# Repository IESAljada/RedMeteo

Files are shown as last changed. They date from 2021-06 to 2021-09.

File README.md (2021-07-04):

# RedMeteo
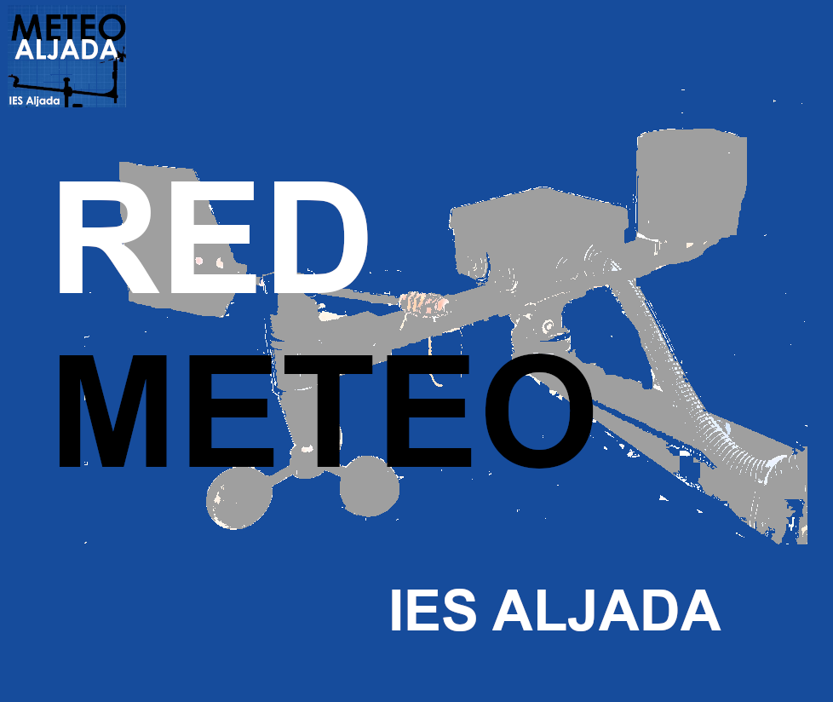
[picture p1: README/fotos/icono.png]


# Objetivo
Con esta experiencia, intentamos trabajar los Objetivos de Desarrollo Sostenible. Deben ser el hilo conductor para lograr avanzar en la sociedad. El trabajo en estos ODS son la base para obtener una sociedad crítica y reivindicativa y así para seguir avanzando.
Con esta experiencia pretendemos establecer una red de centros interconectados con un nexo en común: la concienciación de las nuevas generaciones en la defensa de nuestro mundo. Esta experiencia pretende la educación integral de las nuevas generaciones, diseñando, estudiando, creando y evaluando nuestro entorno.
La tecnología es el punto de partida, pero no es el fin.
La estación meteorológica de la que partimos esta instalada en el IES Aljada de Puente Tocinos.

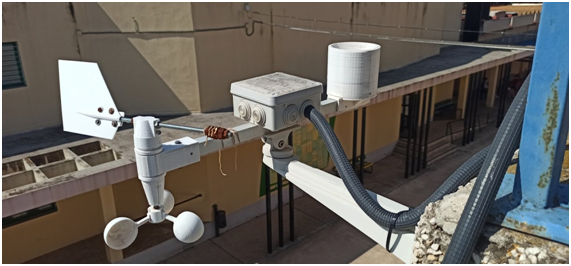
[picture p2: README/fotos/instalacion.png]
 

Un ejemplo de los datos que está ofreciendo nuestra estación los puedes consultar en: https://thingspeak.com/channels/1286958 

# Hardware
## Piezas 3 D 
[Link a Piezas 3D](https://github.com/IESAljada/RedMeteo/tree/main/Piezas_3D)

Todas las piezas han sido diseñadas e impresas con una impresora 3d.  Existen archivos para ser distribuidos con todas las piezas:

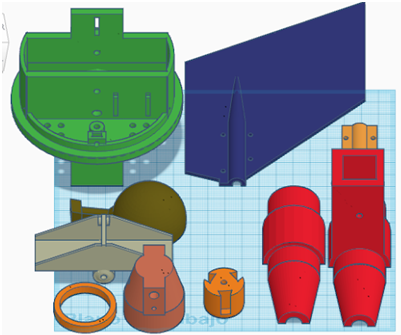
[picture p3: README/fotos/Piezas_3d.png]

 
# Electrónica
[Link a Hardware](https://github.com/IESAljada/RedMeteo/tree/main/Hardware)

Estas piezas se montan sobre una barra de aluminio y se introducen sensores para la toma de datos que van a ser gestionados con un Arduino uno instalado en una caja:

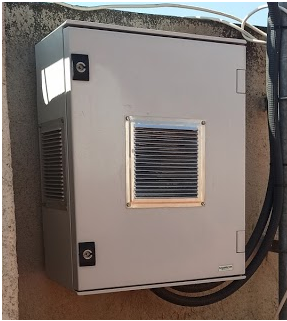
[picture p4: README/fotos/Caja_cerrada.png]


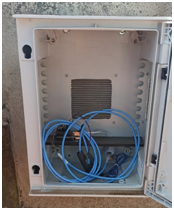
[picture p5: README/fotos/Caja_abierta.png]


Esta caja está instalada en una pared, preferiblemente dando al norte ya que dentro hay un sensor de temperatura y humedad.

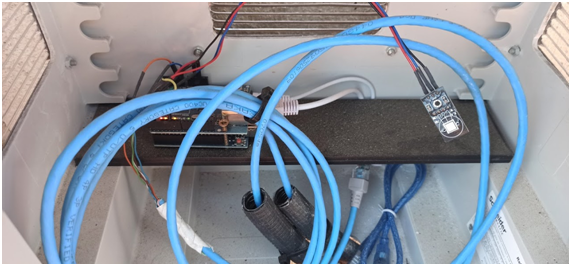
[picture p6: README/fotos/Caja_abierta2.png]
 
 
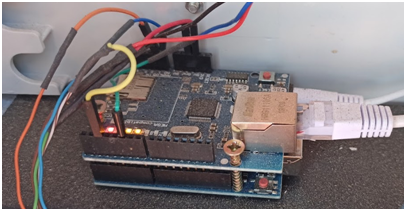
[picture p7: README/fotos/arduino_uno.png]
 

La relación de dispositivos electrónicos necesarios se describe en un archivo adjunto con su presupuesto.

El circuito eléctrico con todas las conexiones es:

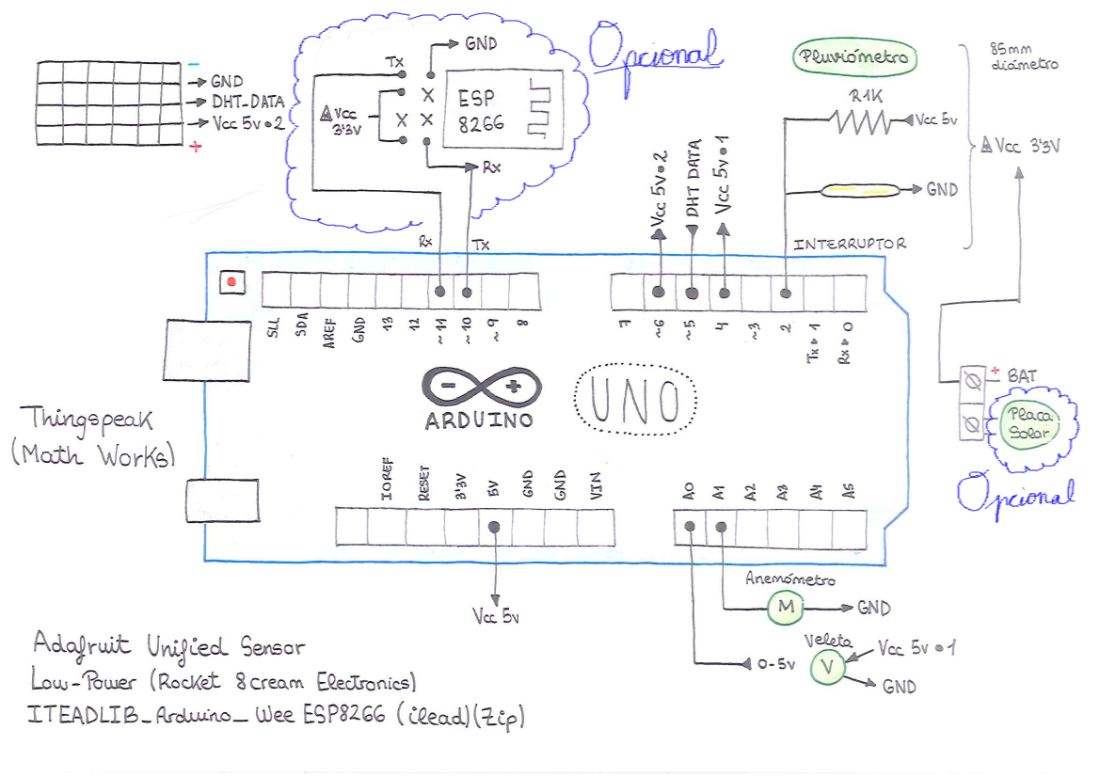
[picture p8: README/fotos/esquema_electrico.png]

 
# Software
[Link a Software](https://github.com/IESAljada/RedMeteo/tree/main/Software)

Otro campo interesante en la formación de los alumnos es el software. Empezar entendiendo el funcionamiento del programa es el inicio para despertar inquietudes y empezar a realizar pequeñas modificaciones sobre el programa base que permitirán a los alumnos adentrarse en esta disciplina. El programa aparece comentado en un archivo adjunto.

La central se conecta a internet, para ello se necesita tener un cable de red conectado a la placa.
Los datos se envían periódicamente a Thingspeak. Donde previamente se ha creado una cuenta y se han definido los campos que se van a mostrar. La creación de la cuenta aparece descrita en un archivo adjunto.

Ahora ya solo la imaginación es el límite, podemos empezar a compartir datos, experiencias, etc

# Funcionamiento

En el siguiente [link](https://github.com/IESAljada/RedMeteo/tree/main/Funcionamiento) se encuentra una explicación más detallada del funcionamiento así como varios videos donde los profesores y alumn@s describen los problemas encontrados y las soluciones aportadas.

# **Ánimo, esto empieza ahora…..** 

[Versión pdf](README/RedMeteo.pdf)

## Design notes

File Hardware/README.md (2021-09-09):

# Hardware

## Electronica

Los dispositivos electrónicos necesarios así como un presupuesto de ellos y la dirección web donde encontrarlos está en la siguiente tabla:
**Observación:** Hay varios precios dependiendo de donde se compre el artículo.

Dispositivo | Descripción | Presupuesto | Link de compra
------------|--------|-------------|---------------
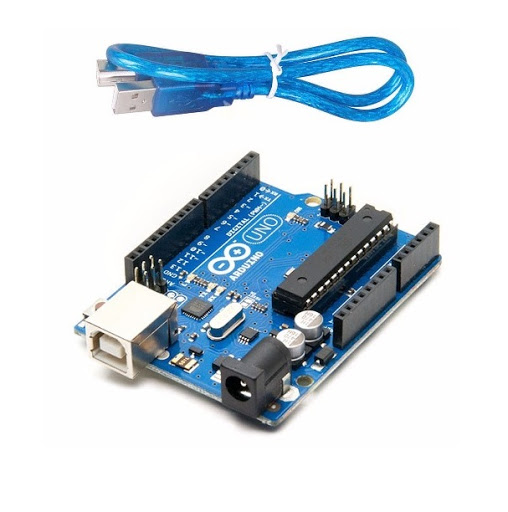
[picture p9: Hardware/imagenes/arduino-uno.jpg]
 |Arduino Uno  | 9,90 € (8,90 € con el cable incluido) | [ElectroHobby tienda española](https://www.electrohobby.es/placas-arduino/36-clon-r3.html) /  ([Aliexpress](https://es.aliexpress.com/item/32831857482.html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) )
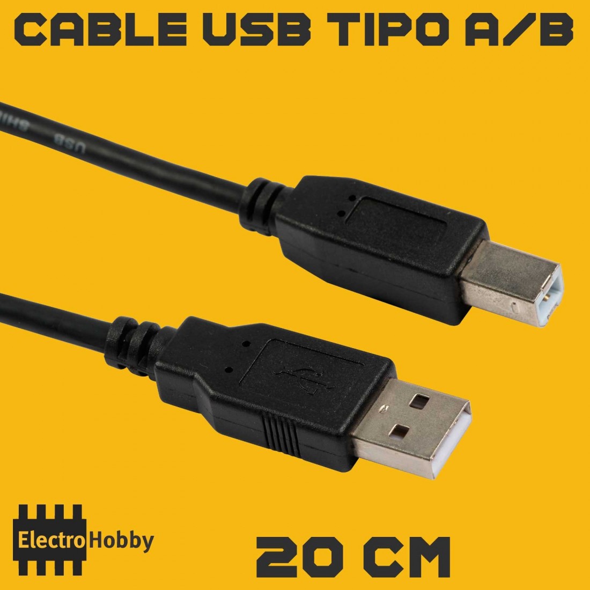
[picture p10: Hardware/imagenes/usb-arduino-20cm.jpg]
 | Cable |1 € | [ElectroHobby tienda española](https://www.electrohobby.es/para-arduino/42-usb-arduino-20cm.html)
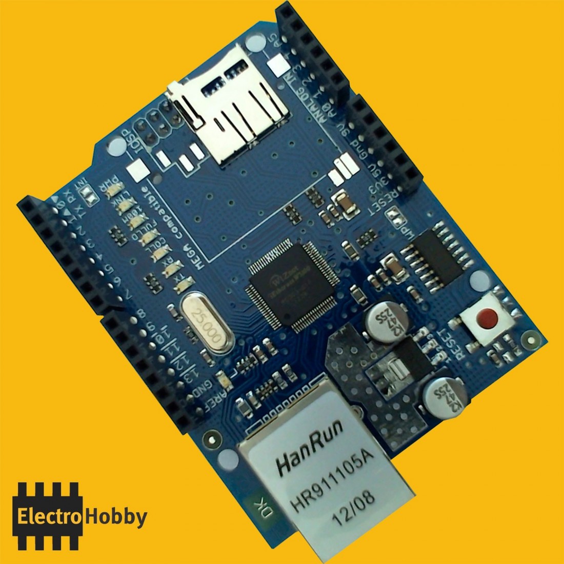
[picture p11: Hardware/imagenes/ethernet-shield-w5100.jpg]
|Tarjeta de Red W5100 |7,40 € | [ElectroHobby tienda española](https://www.electrohobby.es/shield-arduino/38-ethernet-shield-w5100.html)
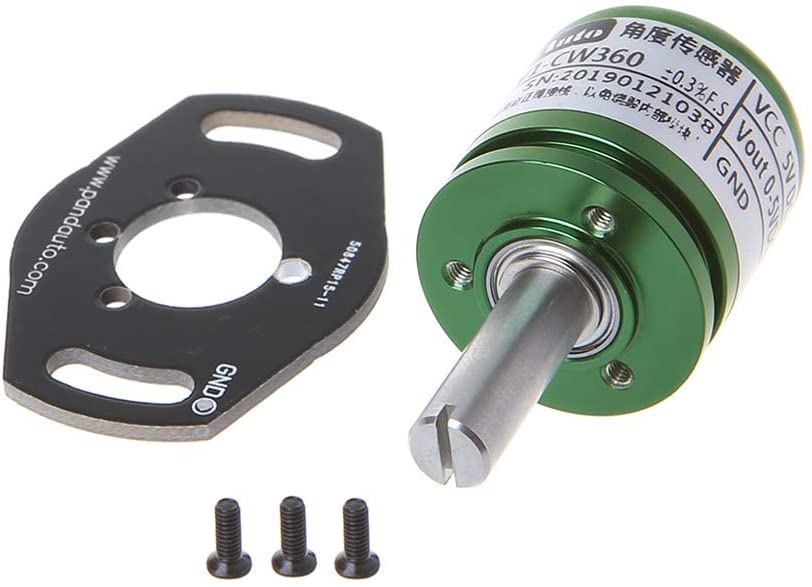
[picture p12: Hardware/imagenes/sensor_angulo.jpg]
|Sensor ángulo de efecto Hall | 19,44 € | [Amazon](https://www.amazon.es/Kcnsieou-Potenci%C3%B3metro-anal%C3%B3gico-desplazamiento-rotaci%C3%B3n/dp/B08FRJCTZZ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)
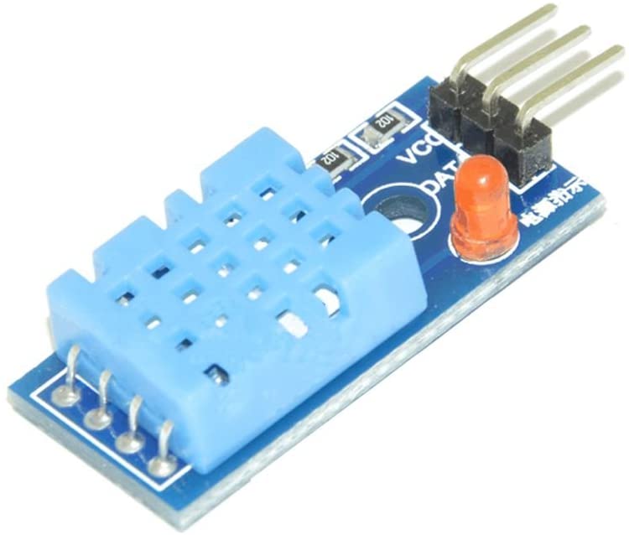
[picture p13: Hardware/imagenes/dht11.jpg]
|Sensor de humedad y temperatura | 3,59 € (1,70 €) | [Amazon](https://www.amazon.es/Guangcailun-Digital-Temperatura-Relativa-Humedad/dp/B08H7HJQ79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) ([Aliexpress](https://es.aliexpress.com/item/32945476028.html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))
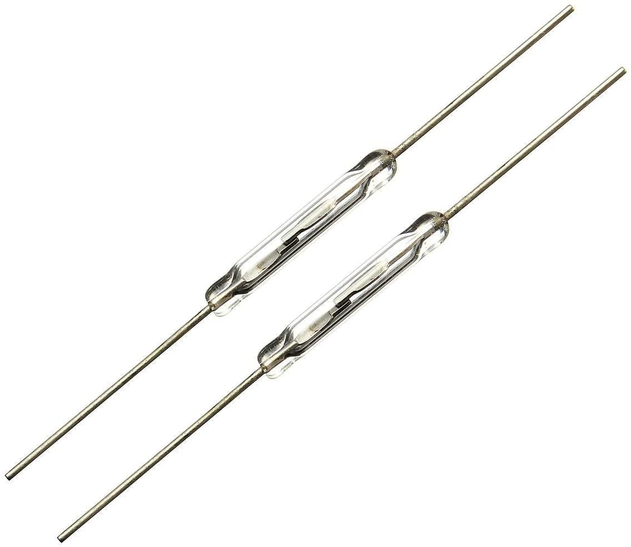
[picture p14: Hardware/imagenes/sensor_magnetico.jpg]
|Sensor magnético para contador pluviómetro | 3,67 € (1,40 €)| [Amazon](https://www.amazon.es/gp/product/B01GWJ86O4/ref=ppx_yo_dt_b_asin_title_o04_s00?ie=UTF8&psc=1) ([Aliexpress](https://es.aliexpress.com/item/4000217757828.html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))
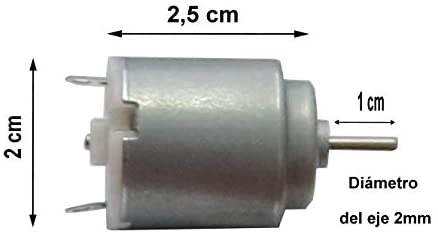
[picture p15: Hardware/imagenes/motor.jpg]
|Motor para el anemómetro| 5,90€  | [Amazon](https://www.amazon.es/Rajotero-Mini-Motor-15000-Motores/dp/B07GPQV6V1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)
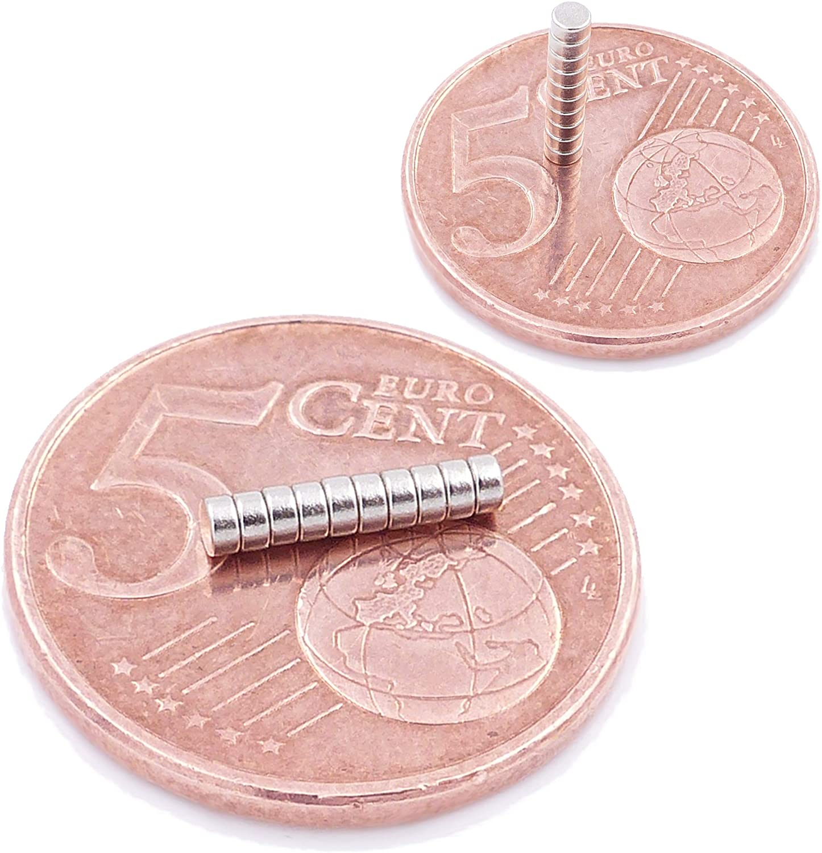
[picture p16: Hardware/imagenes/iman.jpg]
|Imán para contador del pluviómetro | 12,99 € (4,20 €) |[Amazon](https://www.amazon.es/Brudazon-Conjunto-Imanes-Discos-Fuerte/dp/B07M7PWWX5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) ([Aliexpress](https://es.aliexpress.com/item/1005001614055650.html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))
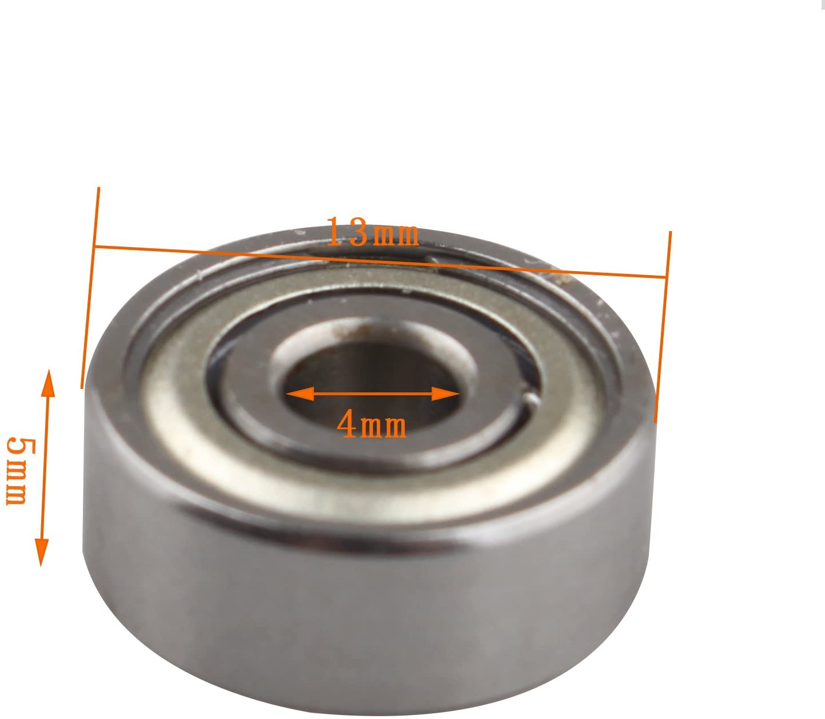
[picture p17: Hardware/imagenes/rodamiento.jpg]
|Rodamiento para el eje de la veleta |9,99 € | [Amazon](https://www.amazon.es/gp/product/B079DL4NKW/ref=ppx_yo_dt_b_asin_title_o05_s00?ie=UTF8&psc=1)
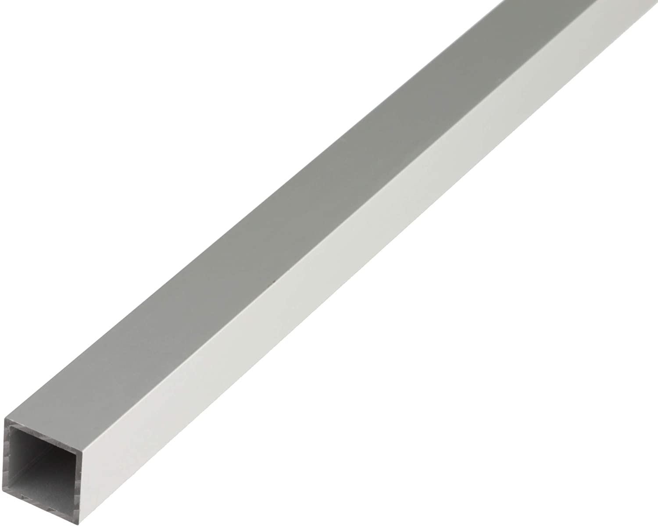
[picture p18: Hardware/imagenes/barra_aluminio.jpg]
|Tubo hueco cuadrado (aluminio)| 15,47 €| [Amazon](https://www.amazon.es/gp/product/B0029ZV8YQ/ref=ppx_yo_dt_b_asin_title_o05_s01?ie=UTF8&psc=1)
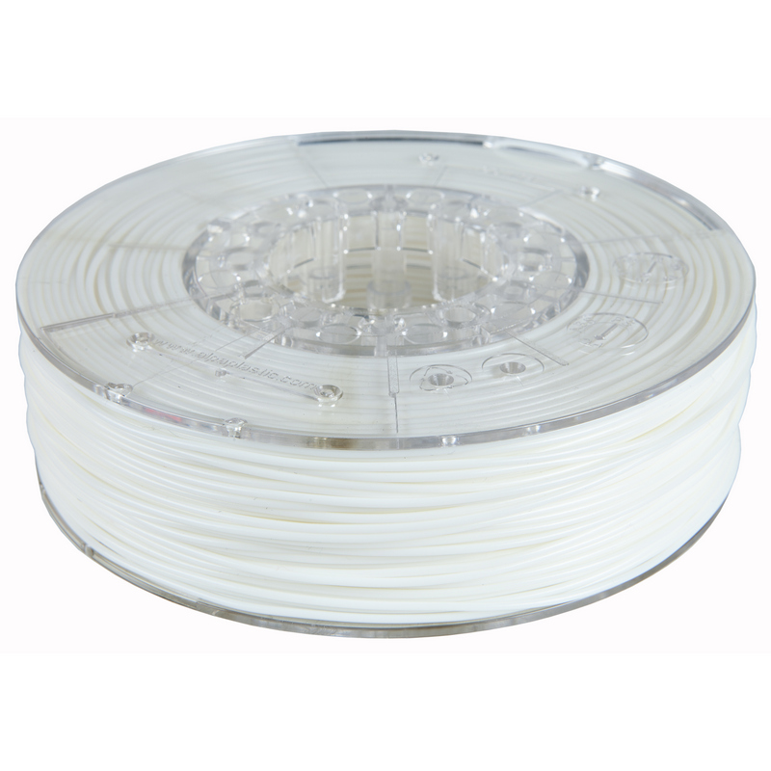
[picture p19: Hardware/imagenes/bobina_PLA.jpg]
|Bobina PLA para la impresora 3D| 19,99€  | [PC Componentes](https://www.pccomponentes.com/sakata-3d-bobina-de-filamento-pla-3d850-175mm-blanco-1kg)
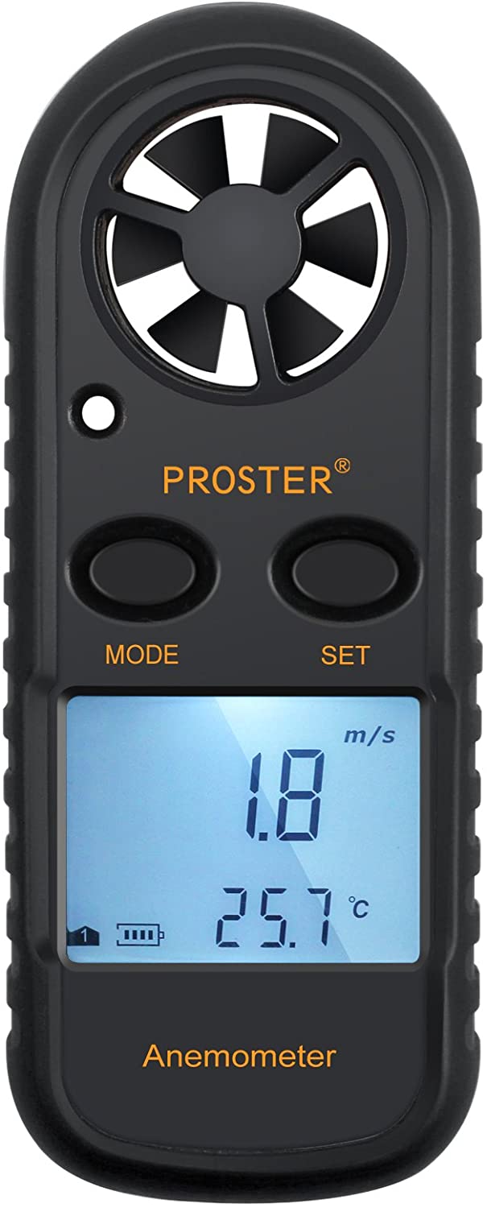
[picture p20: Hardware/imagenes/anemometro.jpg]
|Anemámetro digital (para calibrar)| 21,99€  | [Amazon](https://www.amazon.es/Anem%C3%B3metro-Term%C3%B3metro-Digital-Pantalla-Velocidad/dp/B0761NK4GH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)
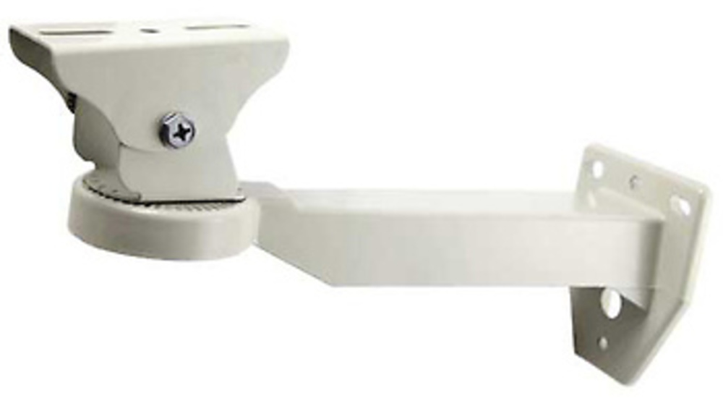
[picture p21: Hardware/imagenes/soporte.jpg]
|Soporte estación metereológica| 17,24€  | [IpCenter](https://www.ipcenter.es/ib-06.html)

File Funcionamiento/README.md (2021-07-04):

# Funcionamiento
<p align="center">(Si pulsas en las imágenes se repruducirá el vídeo)</p>

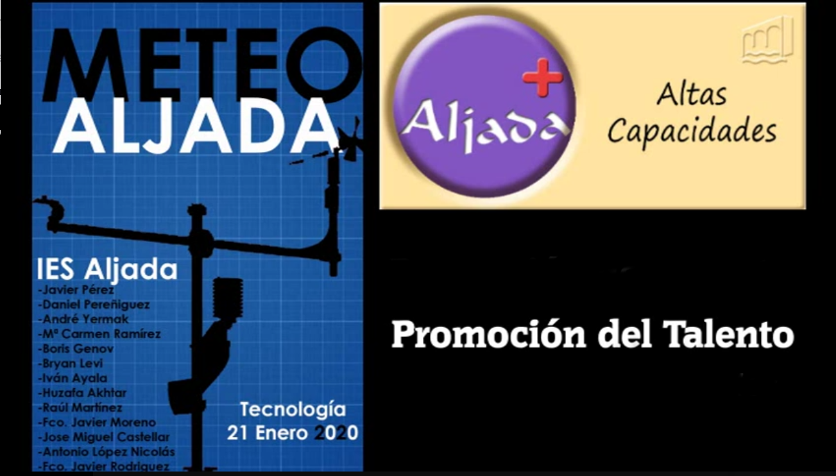
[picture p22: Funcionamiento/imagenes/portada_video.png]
[](https://www.youtube.com/watch?v=M3VhcBCXWJw) 

## Anemómetro
Nuestro anemometro consiste en tres "cucharas" imprimidas con la impresora 3D del instituto unidas a un pequeño motor

Se trata de un motor que funciona como una dinamo que emite una variacion de voltage que se ha mapeado para dar los valores lo mas reales posibles . Básicamente para poder ajustar se ha hecho lo siguiente: se ha cogido un anemómetro profesional a una distancia X de una fuente de viento, se ha utilizado un compresor de aire para que siempre sople con la misma fuerza y al lado el anemómetro de la estación a la misma distancia ; se registran los datos (el voltage obtenido del anemómetro de la estación con la velocidad obtenida en uno profesional).

## Veleta
La veleta funciona con un potenciómetro efecto hall rotativo por lo que cada posición tiene un voltaje
 distinto que va desde 0 hasta – 5 voltios. El programa mapea estos datos para asociar el valor de voltaje
 a  un valor previamente calibrado con una brújula. 
También se ha calibrado para que el centro de masas se encuentre en el eje del sensor. 

### Explicación de programación.
1. Establecemos las variables a utilizar. Las que vayan acompañadas de “#define” serán aquellas asociadas al arduino y las que vayan con “float” serán utilizadas en el programa cuyos valores serán expresados con números decimales.
1. Dentro de la estructura  “voidsetup” determinaremos los comandos que deberán activarse para iniciar el programa. De esta forma arduino enviará la señal de “inicializando”..
1. Creamos una función que llamaremos “HacerLecturas”. El programa lee el valor analógico del sensor y lo transformará mediante la función mapeo el voltaje recibido del potenciómetro en grados norte. Al valor obtenido se le dará la variable “direccion”. Los valores de voltaje preestablecidos son calibrados mediante una brújula.
1. Dentro de la estructura “voidloop” el programa ejecutará la función “HacerLecturas” y ésta escribirá en el monitor los datos recibidos. Finalmente al usar el comando “Seria.println” los datos aparecerán separados por espacios.
### Explicación del funcionamiento.
La veleta funciona con un potenciómetro efecto hall rotativo por lo que cada posición tiene un voltaje distinto que va desde 0 hasta – 5 voltios. 
El programa mapea estos datos para asociar el valor de voltaje a  un valor previamente calibrado. 
También se ha calibrado para que el centro de masas se encuentre en el eje del sensor. 

## Pluviómetro
El pluvionetro tiene la función de medir la cantidad de agua acumulada por superficie durante las precipitaciones. El agua de la lluvia se almacena en una especie de depósito y al estar este lleno se vacia y se inclina para que el otro depósito se vuelva a llenar y así sucesivamente mientras llueva. Por medio de varias funciones del arduino en el que se asignan variables, se puede puede programar una ecuación, mediante un sensor magnético se mide la diferencia de voltaje entre el tiempo, atraves de una ecuación podemos calcular la precipitación en "mm/h". 

Comenzamos definiendo la función #define, la cual,  es un componente útil que permite al programador dar un nombre a un valor constante antes de compilar el programa, en este caso es "PLUVIOMETRO_IN" con un valor de 2.
Proseguimos asignando las variables "lluvia" , "tiempo1" y "tiempo2"  como un valor float, es decir, un valor que posee decimales.
Ahora, nos adentramos en la función setup. El setup es la primera función en ejecutarse dentro de un programa en Arduino. Es, básicamente, donde se "setean" las funciones que llevará a cabo el microcontrolador. En primer lugar, llamamos al monitor serie mediante la función "Serial.begin()", con un valor de 9600 bps. Después ordenamos a la Arduino a escribir “Inicializando…” mediante el comando Serial.println(). Seguimos asignando el pin al que vamos a conectar el controlador que vamos a utilizar, en este caso, un sensor magnético, que lo vamos a conectar en el pin 2, definido anteriormente, e interrumpimos el pluviómetro mediante el comando INPUT_PULLUP.

Seguimos con la función "calcular_lluvia", en la que por su propio  nombre indica, es una función creada para calcular el nivel de lluvia.
En esta función, comenzamos igualando la variable "tiempo2" a la función "millis()" , la cual asigna el tiempo medido en la variable "tiempo2" a milisegundos.

Ahora hemos utilizado un condicional para calcular la lluvia: Si el tiempo2 es mayor que el tiempo1 y restando el tiempo2 menos el tiempo1 es mayor o igual a 120, entonces:

Escribimos el valor de "tiempo1" y el de "tiempo2". Tras esto realizamos la ecuación de la lluvia:  *lluvia = 6*158.57*3600/(tiempo2-tiempo1)*

Tras haber realizado esta ecuación,  imprimimos su valor en el monitor serie, acompañado de su medida "mm/h". E igualamos los tiempos, "tiempo1 = tiempo2".

El pluviómetro mide la cantidad de lluvia en función del tiempo aplicando la fórmula anterior. En el interior del pluviometro tenemos implantado un  sensor magnético que mide la diferencia de voltaje entre el tiempo,  que cuando se llena una parte del cubo, se vacía y en el tiempo que tarda en bajar detecta ese tiempo y lo implementa en la ecuación para calcular la lluvia.

Detalle del montaje del anemómetro y la veleta con los dos anillos que entran a presión y la junta hecha de *goma Eva* entre las dos piezas para intentar crear una zona estanca ya que ahí están alojados el motor y el sensor angular, *tal vez esta es la zona más débil del proyecto*:

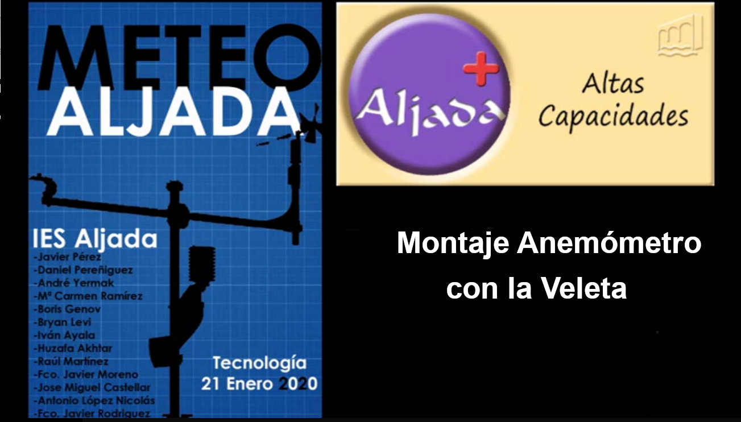
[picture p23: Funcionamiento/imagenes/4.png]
[](https://www.youtube.com/watch?v=L_95Tg8eJ-M)

## Sensor de temperatura y humedad (DHT11)
El DHT11 es un sensor de temperatura y humedad que dispone de una salida calibrada a una señal digital.
 Este dispositivo puede medir la temperatura de un área dada, y para hacer un mayor rendimiento de esa área, lo hemos cambiado de lugar a una caja ventilada, para tener una medida lo más precisa posible. En esta caja también estará el arduino.

Respecto a la programación utilizamos librerías como el comando "#define DHT_PINS "y los comandos "Serial.print", "Serial.println" y "read" para que el arduino lea y envie estos datos.

# Vídeos del proyecto

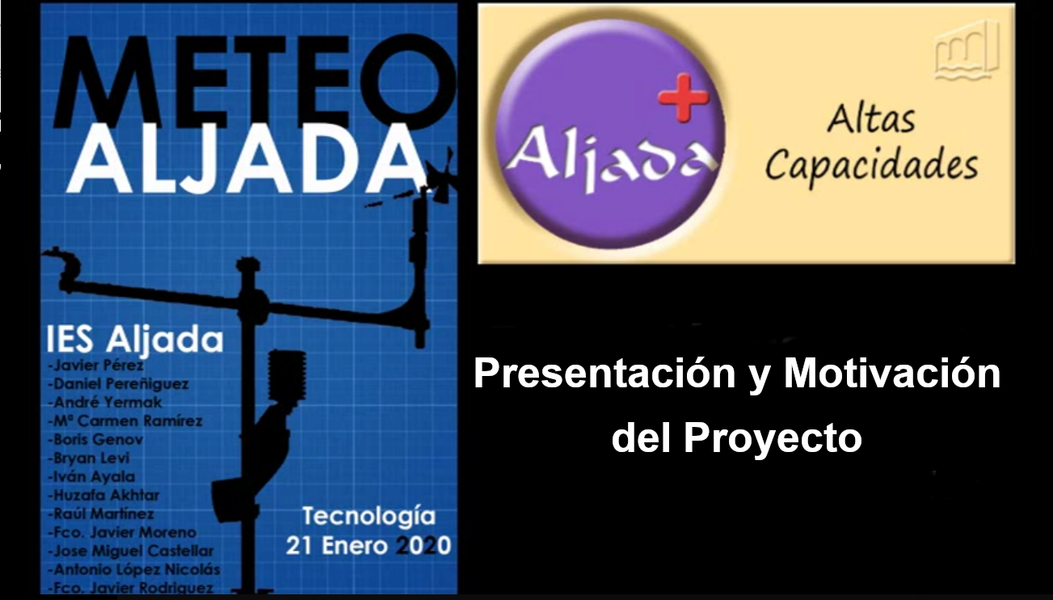
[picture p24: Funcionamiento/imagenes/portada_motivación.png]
[](https://www.youtube.com/watch?v=khU9boEUZWA)

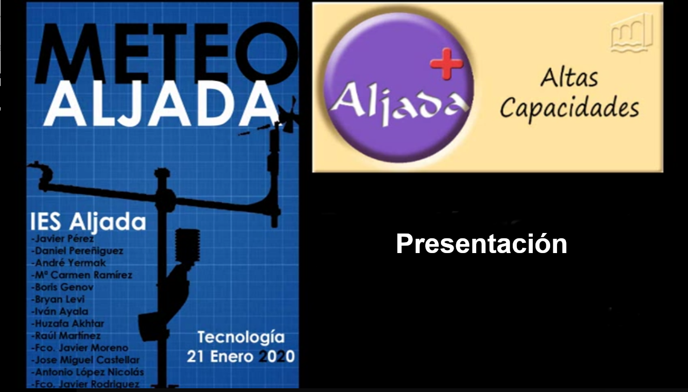
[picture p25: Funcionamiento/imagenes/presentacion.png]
[](https://www.youtube.com/watch?v=QIYsvqj47zA)

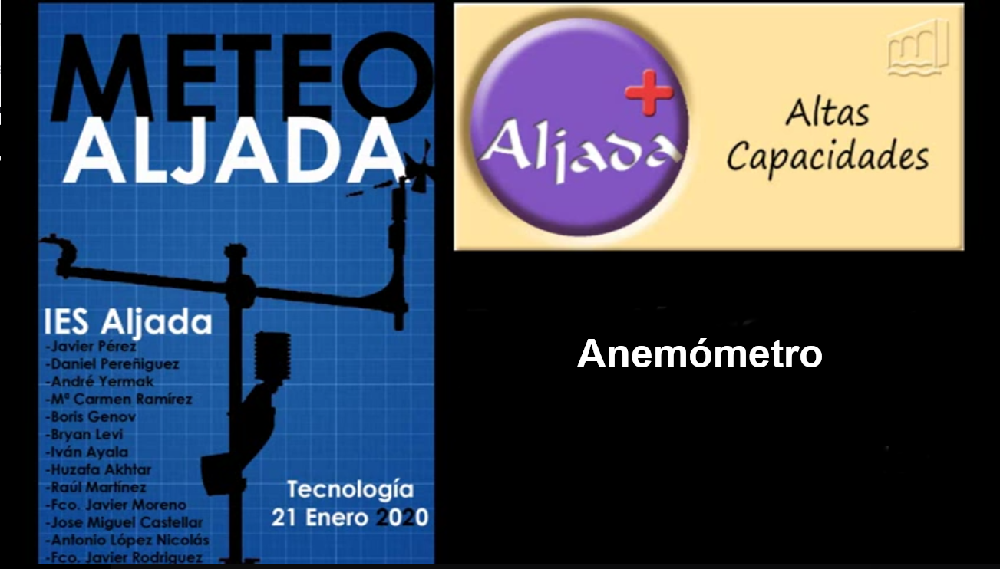
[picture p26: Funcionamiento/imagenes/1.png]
[](https://www.youtube.com/watch?v=qWfMcAfXikM)

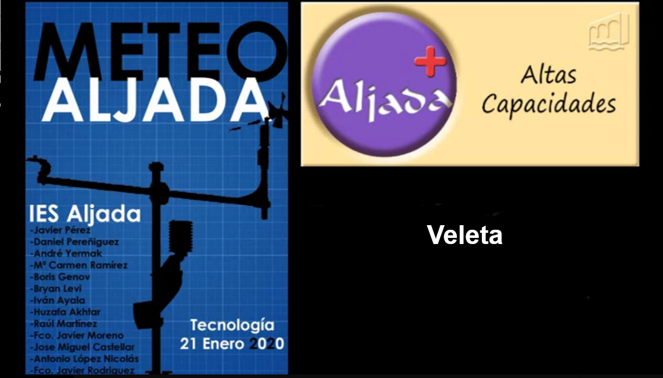
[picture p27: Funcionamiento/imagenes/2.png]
[](https://www.youtube.com/watch?v=wo1Z4RKRpvQ)

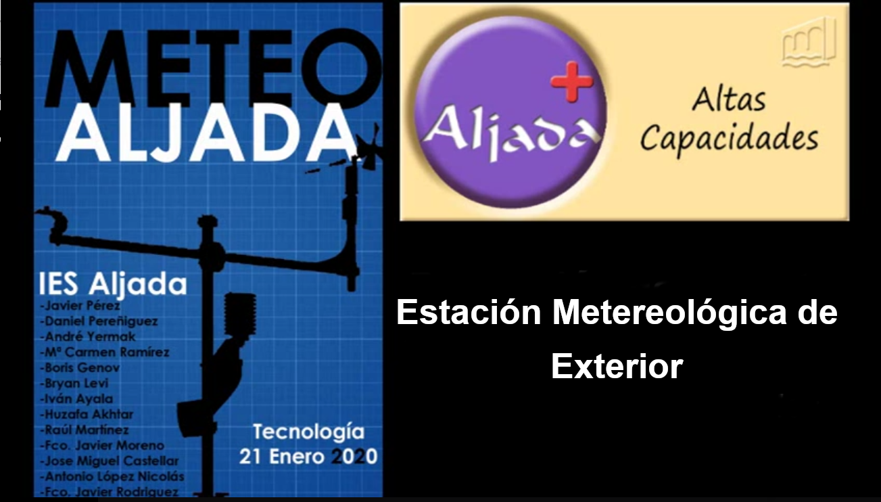
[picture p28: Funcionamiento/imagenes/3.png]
[](https://www.youtube.com/watch?v=ot10pqSaxAg)

# Enlace ThinkSpeak

Los datos obtenidos con la estación son introducidos en un servidor web desde donde se hacen públicos y son accesibles desde el exterior. Para ello hay que crearse una cuenta en ThinkSpeak. En el siguiente manual se describen todos los pasos. [Creación Cuenta Thingspeak](creacion_cuenta.md)

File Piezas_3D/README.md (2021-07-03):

# Piezas 3D

En este directorio, puedes encontrar las piezas 3D en ficheros stl. Este formato es reconocido por la mayoría de 
los programas de diseño **CAD** tipo Autocad.
Las piezas son:

## **Archivo:** [*balancin.stl*](https://github.com/IESAljada/RedMeteo/blob/main/Piezas_3D/balancin.stl)
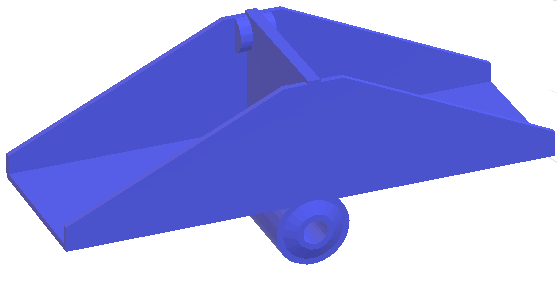
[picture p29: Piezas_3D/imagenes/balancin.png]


## **Archivo:** [*base_anem_veleta.stl*](https://github.com/IESAljada/RedMeteo/blob/main/Piezas_3D/base_anem_veleta.stl)

  <p align="center">
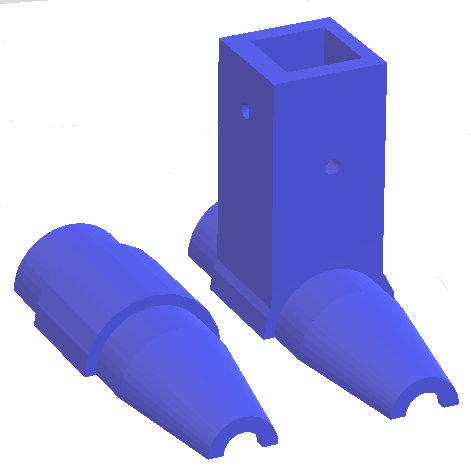
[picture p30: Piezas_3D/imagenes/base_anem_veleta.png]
    </p>

## **Archivo:** [*base_pluviometro.stl*](https://github.com/IESAljada/RedMeteo/blob/main/Piezas_3D/base_pluviometro.stl)
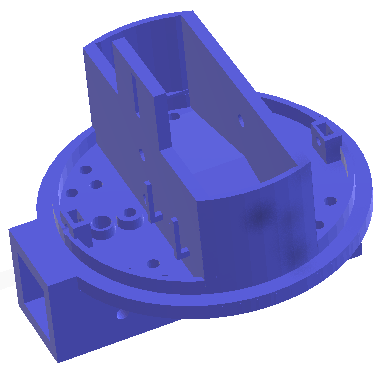
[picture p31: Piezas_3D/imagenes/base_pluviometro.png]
<p align="center">

## **Archivo:** [*brida.stl*](https://github.com/IESAljada/RedMeteo/blob/main/Piezas_3D/brida.stl)
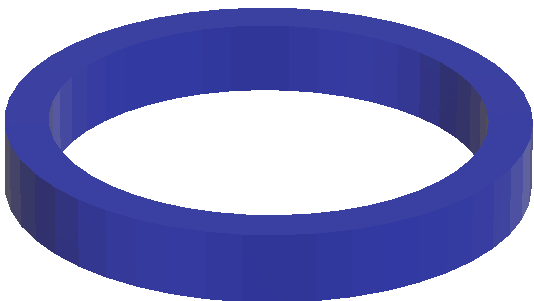
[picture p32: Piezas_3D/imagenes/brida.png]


## **Archivo:** [*capsula_pluviometro.stl*](https://github.com/IESAljada/RedMeteo/blob/main/Piezas_3D/capsula_pluviometro.stl)


## **Archivo:** [*conector_anem.stl*](https://github.com/IESAljada/RedMeteo/blob/main/Piezas_3D/conector_anem.stl)


## **Archivo:** [*paletas_anem.stl*](https://github.com/IESAljada/RedMeteo/blob/main/Piezas_3D/paletas_anem.stl)


## **Archivo:** [*soporte_veleta.stl*](https://github.com/IESAljada/RedMeteo/blob/main/Piezas_3D/soporte_veleta.stl)


## **Archivo:** [*veleta.stl*](https://github.com/IESAljada/RedMeteo/blob/main/Piezas_3D/veleta.stl)


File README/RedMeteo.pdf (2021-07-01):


# Objetivo

Con esta experiencia, intentamos trabajar los Objetivos de Desarrollo Sostenible. Deben ser el hilo conductor para lograr avanzar en la sociedad. El trabajo en estos ODS son la base para obtener una sociedad crítica y reivindicativa y así para seguir avanzando.
Con esta experiencia pretendemos establecer una red de centros interconectados con un nexo en común: la concienciación de las nuevas generaciones en la defensa de nuestro mundo. Esta experiencia pretende la educación integral de las nuevas generaciones, diseñando, estudiando, creando y evaluando nuestro entorno.
La tecnología es el punto de partida, pero no es el fin.
La estación meteorológica de la que partimos esta instalada en el IES Aljada de Puente Tocinos.

## Hardware

## Piezas 3 D

Todas las piezas han sido diseñadas e impresas con una impresora 3d. Existen archivos para ser distribuidos con todas las piezas:


## Electrónica

Estas piezas se montan sobre una barra de aluminio y se introducen sensores para la toma de datos que van a ser gestionados con un Arduino uno instalado en una caja:
Esta caja está instalada en una pared, preferiblemente dando al norte ya que dentro hay un sensor de temperatura y humedad.


La relación de dispositivos electrónicos necesarios se describe en un archivo adjunto con su presupuesto.
El circuito eléctrico con todas las conexiones es:

## Software

Otro campo interesante en la formación de los alumnos es el software. Empezar entendiendo el funcionamiento del programa es el inicio para despertar inquietudes y empezar a realizar pequeñas modificaciones sobre el programa base que permitirán a los alumnos adentrarse en esta disciplina. El programa aparece comentado en un archivo adjunto.

La central se conecta a internet, para ello se necesita tener un cable de red conectado a la placa.
Los datos se envían periódicamente a Thingspeak. Donde previamente se ha creado una cuenta y se han definido los campos que se van a mostrar. La creación de la cuenta aparece descrita en un archivo adjunto.

Ahora ya solo la imaginación es el límite, podemos empezar a compartir datos, experiencias, etc

Ánimo, esto empieza ahora…..

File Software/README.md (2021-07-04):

# Software

El programa fué modificado tras comprobar que daba error, no subía a ThinkSpeak las lecturas y se bloqueaba (sin motivo aparente). 
Comprobé que si lo hacía directo con una solicitud POST de HTTP las cosas funcionaban mejor.

Hay un archivo llamado **secrets.h** donde hay que introducir unos códigos:
Constante|Valor
---------|-----
SECRET_CH_ID | Tu número de canal de ThinkSpeak
SECRET_WRITE_APIKEY | Tu clave para escribir (write API Key)

Y en el programa principal hay que cambiar la dirección IP si se desea que tenga una dirección fija en la red local el arduino uno.
    
    // Set the static IP address to use if the DHCP fails to assign
    IPAddress ip( 0, 0, 0, 0);
    IPAddress myDns( 0, 0, 0, 0);

## Software auxiliar

En la carpeta **pruebas** hay programas para comprobar y ajustar el funcionamiento de los sensores:
* prueba_anemometro.ino
* prueba_dht11.ino
* prueba_pluviometro.ino

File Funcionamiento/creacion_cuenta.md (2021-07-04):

# Publicar los Datos
Para la publicación de los datos obtenidos por la central metereológica se ha optado por hacerlo a través de un servidor externo al proyecto. [ThingSpeak](https://thingspeak.com/).

Veamos una breve descripción de los pasos a seguir para lograr la conexión con este servidor.

## Creación de una Cuenta en ThingSpeak
* Accedemos a la página web: https://thingspeak.com/ 
  <p align="center">
* Pulsamos en el boton que aparece en verde en la parte inferior "Get Started for Free" y llegamos a:
  <p align="center">
* Pulsamos en "No account? Create one!":
  <p align="center"> 
* Completamos los datos y confirmamos nuestro email. Cuando metemos los datos nos presenta un aviso debido a que detecta que es un email personal, solo tenemos que pusar en:
  <p align="center"> 
* Llegamos a una página donde se nos pide la verificación de nuestro email. 
  <p align="center">  
* Cuando pinchamos en el enlace recibido en el correo, obtendrémos una página dondes se nos confirma la verificación de nuestra cuenta:
  <p align="center">  
* Cerramos esta pestaña y volvemos a la anterior, ahora si que pulsamos el botón continue. Se abrirá una última página en la que pondrá "Finish your profile"
    y aquí escribiremos la contraseña que queramos para acceder a nuestra cuenta, aceptando en la casilla de "Online Services Agreement"
    y presionaremos el botón "Continue".
  <p align="center">  
* Ya tenemos la cuenta creada, no lo confirma la página con:
  <p align="center">  
* Nos piden que completemos una pequeña encuesta, la cual contestaremos así:
 <p align="center"> 
   
## Creación de un Canal
   
   Una vez creado una cuenta en ThingSpeak. Ahora, tenemos que crear un canal donde se alojarán los datos de nuestra estación metereológica. 
   Para ello seguimos  las siguientes instrucciones:
   * Entramos con nuestro email y contraseña en nuestra cuenta de ThingSpeak.
   * Pulsamos en:
   
   * Llegamos a una pagina donde se nos piden los datos de nuestro canal:
     
   * Completamos los datos de nuestra estación: Nombre, pequeña descripción, los campos (Field X) que va a ir recogiendo nuestra estación (pueden ser hasta 8 campos),... Y pulsamos en "Save Channel" .
     
   * Llegaremos al canal. *MUY IMPORTANTE* pulsamos en * **API Keys** *:
      
   * Nos apuntmos nuestra Key que necesitaremos para ponerla en nuetro programa  junto con el * **Channel ID** *:   
      
      
## Actualización del Software

Con los datos btenidos anteriormente: *Channel ID*: XXXXXXX y *API Key*: 1234567890ABCDEF modificamos las constantes con esos valores en el archivo del programa **secrets.h** líneas 9 y 10:

    #define SECRET_CH_ID XXXXXXX		        // replace 0000000 with your channel number
    #define SECRET_WRITE_APIKEY "1234567890ABCDE"   // replace XYZ with your channel write API Key
    
 ## Visualización de los datos
 
 Los datos se pueden visualizar externamente a traves del servidor ThingSpeak. Con la siguiente dirección podremos ver los resultados que se van recogiendo: https://thingspeak.com/channels/TU_CHANNEL_ID

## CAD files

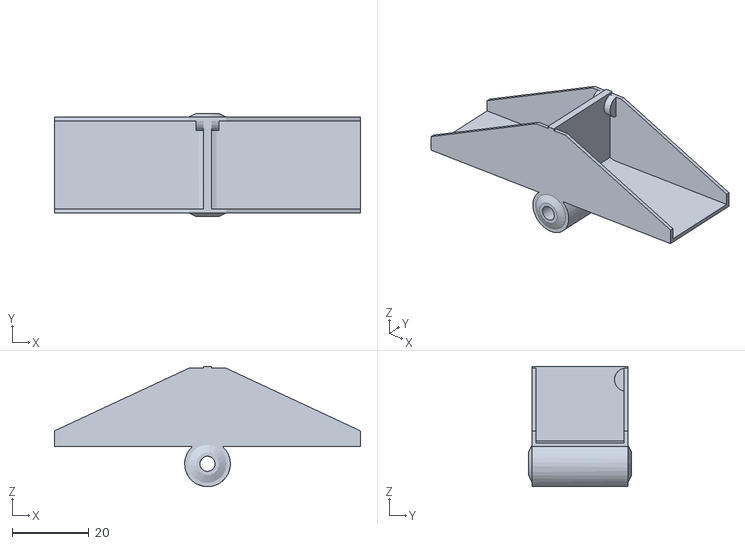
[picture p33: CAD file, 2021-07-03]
Piezas_3D/balancin.stl
80.0 x 27.0 x 31.5

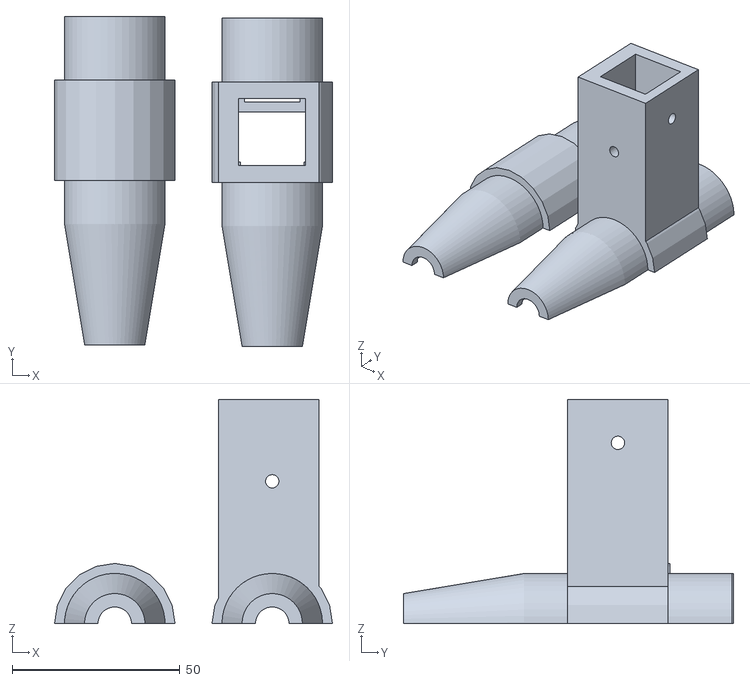
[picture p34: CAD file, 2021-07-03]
Piezas_3D/base_anem_veleta.stl
83.0 x 98.5 x 67.0

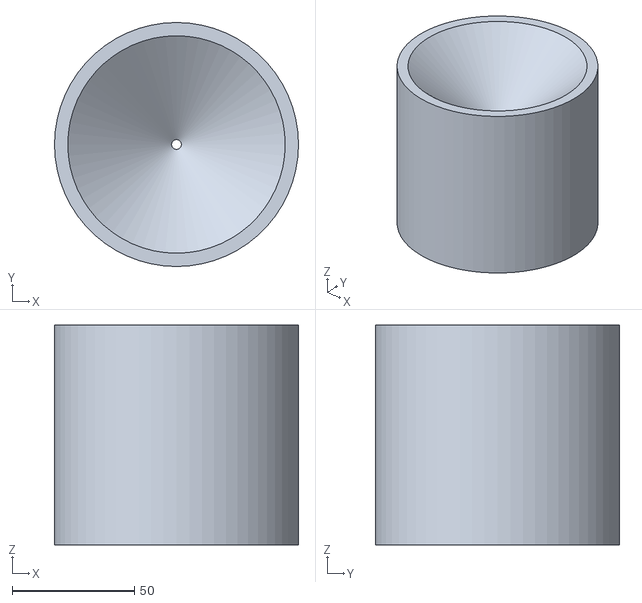
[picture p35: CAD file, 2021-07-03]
Piezas_3D/capsula_pluviometro.stl
100.0 x 100.0 x 90.0

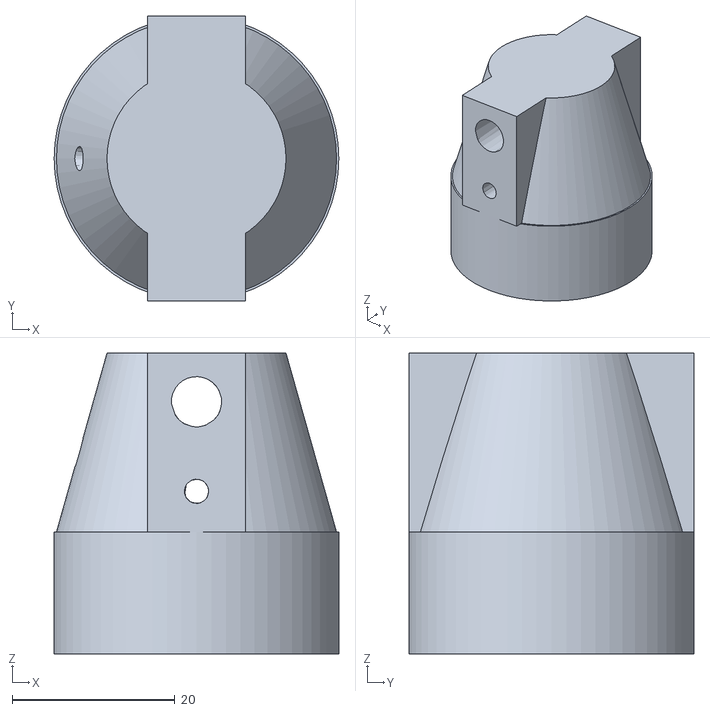
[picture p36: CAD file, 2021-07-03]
Piezas_3D/soporte_veleta.stl
35.0 x 35.0 x 37.0

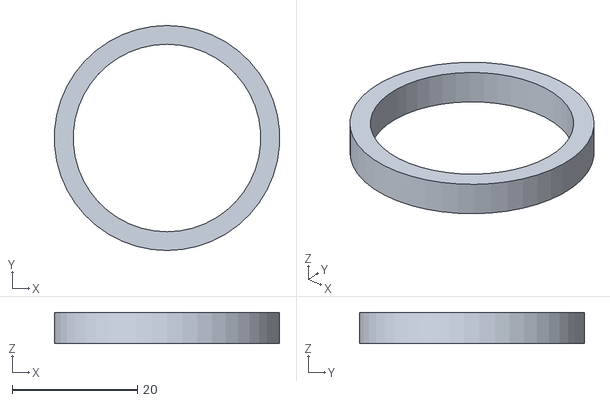
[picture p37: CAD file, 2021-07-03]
Piezas_3D/brida.stl
36.0 x 36.0 x 5.00

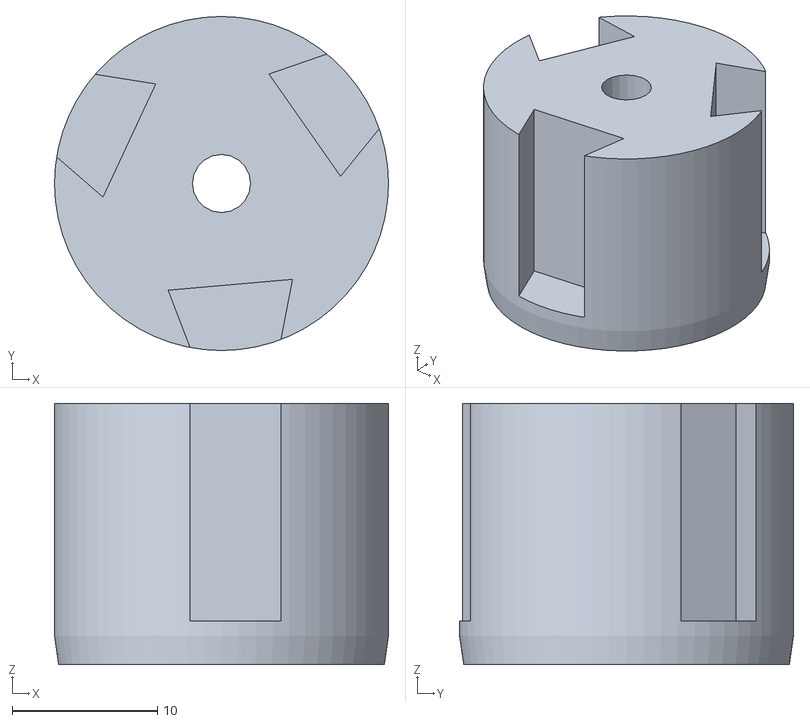
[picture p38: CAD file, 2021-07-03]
Piezas_3D/conector_anem.stl
23.0 x 23.0 x 18.0

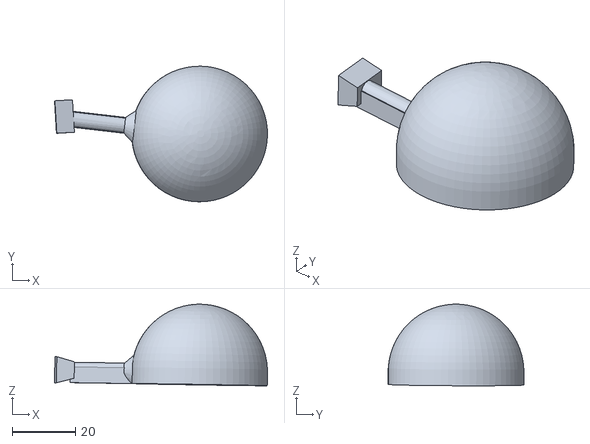
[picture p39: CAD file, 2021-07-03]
Piezas_3D/paletas_anem.stl
67.4 x 43.0 x 25.8

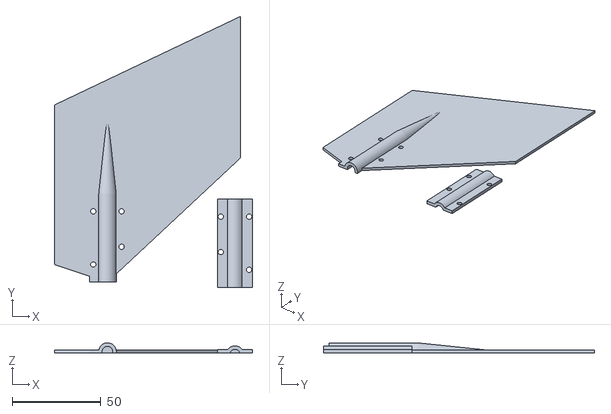
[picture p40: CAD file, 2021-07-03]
Piezas_3D/veleta.stl
112.0 x 153.0 x 5.85

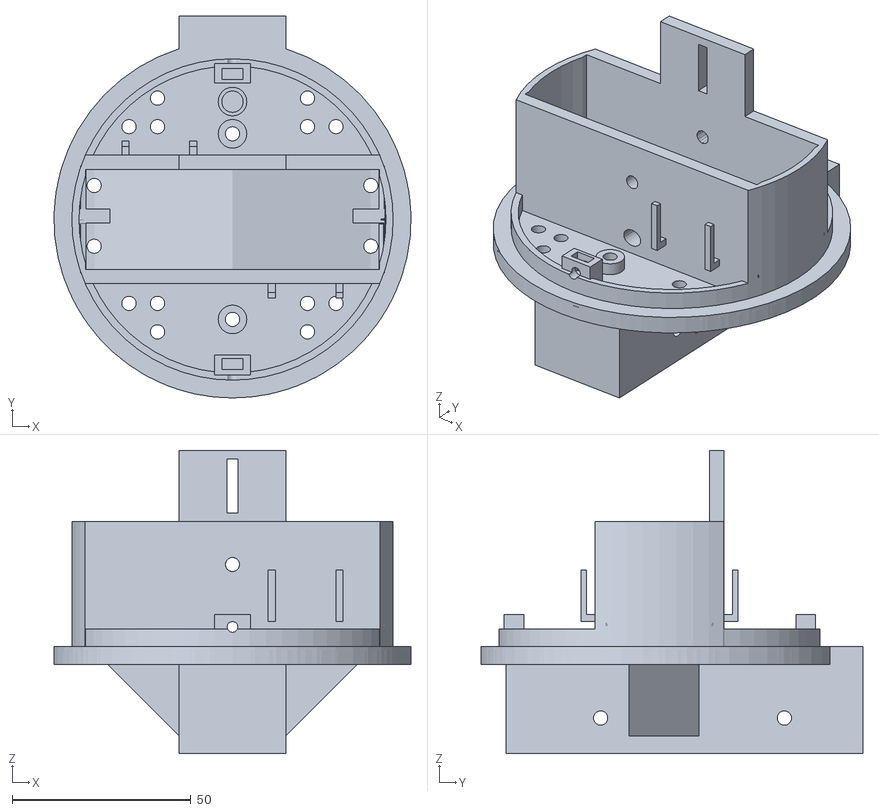
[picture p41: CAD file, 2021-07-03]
Piezas_3D/base_pluviometro.stl
100.0 x 107.0 x 85.0

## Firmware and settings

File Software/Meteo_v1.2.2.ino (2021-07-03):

/*
 * Dirección automática dada desde DHCP y sino está disponible espera hasta que lo este
 * 
 */
#include <Ethernet.h>
#include <DHT.h>

#include "secrets.h"
//#include "ThingSpeak.h"

#define DHT_PIN 5
#define DHT_TYPE DHT11
#define HALL_OUT A0
#define ANEM_OUT A1
#define PLUVIOMETRO_IN 2

#define THING_SPEAK_ADDRESS "api.thingspeak.com"
#define TIMEOUT 5000

byte mac[] = SECRET_MAC;

DHT dht(DHT_PIN, DHT_TYPE);

// Set the static IP address to use if the DHCP fails to assign
IPAddress ip(10,32, 42, 223);
IPAddress myDns(10, 32, 42, 1);
//IPAddress ip(192, 168, 0, 177);
//IPAddress myDns(192, 168, 0, 1);

EthernetClient client;

unsigned long myChannelNumber = SECRET_CH_ID;
//const char * myWriteAPIKey = SECRET_WRITE_APIKEY;

float temp_DHT11, humedad_DHT11, velocidad, direccion, lluvia;
float tiempo1=0, tiempo2;
int offset=0;

void setup() {
  Ethernet.init(10);  // Most Arduino Ethernet hardware
  Serial.begin(115200);  //Initialize serial
  Serial.println("Estación Metereológica versión 1.2.2");
  Serial.println("INICIANDO");
    
  // start the Ethernet connection:
  Serial.println("Initialize Ethernet with DHCP:");
  /*if (Ethernet.begin(mac) == 0) {
    Serial.println("Failed to configure Ethernet using DHCP");
    // Check for Ethernet hardware present
    if (Ethernet.hardwareStatus() == EthernetNoHardware) {
      Serial.println("Ethernet shield was not found.  Sorry, can't run without hardware. :(");
      while (true) {
       delay(1); // do nothing, no point running without Ethernet hardware
     }
    }
    if (Ethernet.linkStatus() == LinkOFF) {
      Serial.println("Ethernet cable is not connected.");
    }
    // try to congifure using IP address instead of DHCP:
    Ethernet.begin(mac, ip, myDns);
  } else {
    Serial.print("  DHCP assigned IP ");
    Serial.println(Ethernet.localIP());
  }*/

  /************************************************
  // Esperar hasta recibir la dirección IP por DHCP
  /*************************************************/

  while(Ethernet.begin(mac)==0)
  {
    if (Ethernet.hardwareStatus() == EthernetNoHardware) {
      Serial.println("Ethernet shield was not found.  Sorry, can't run without hardware. :(");
      while (true) {
       delay(1); // do nothing, no point running without Ethernet hardware
     }
    }
    if (Ethernet.linkStatus() == LinkOFF) {
      Serial.println("Ethernet cable is not connected.");
    }
    delay(1500);
  }
  Serial.print("  DHCP assigned IP ");
    Serial.println(Ethernet.localIP());
  
  // give the Ethernet shield a second to initialize:
  delay(1000);
  
  // ThingSpeak.begin(client);  // Initialize ThingSpeak

  pinMode(PLUVIOMETRO_IN, INPUT_PULLUP);  // Interrupcion pluviometro
  pinMode(DHT_PIN, INPUT);
  attachInterrupt(0, calcular_lluvia, RISING);
  Serial.println("Setup terminado correctamente.");
  dht.begin();
  
  delay(100);
  
 
}

void calcular_lluvia() {
  tiempo2 = millis();
  if (tiempo2 > tiempo1) {lluvia = 7*3600/(tiempo2-tiempo1);}
  tiempo1 = tiempo2;
}

void HacerLecturas() {

  temp_DHT11 = dht.readTemperature();
  humedad_DHT11 = dht.readHumidity();
  //*****************************************
  velocidad = 0.0964*analogRead(ANEM_OUT)+2.0187;
  direccion = map(analogRead(HALL_OUT), 0, 1024, 360-offset, 0-offset);
  if (direccion < 0) {direccion+=360;}
  if((millis()-tiempo1)>=36000000) {lluvia=0;}
  //*******************************************
  //12.6 l/h = 210 l/h
  //0,116 l/h si ponemos una hora

  /*temp_DHT11=random(15.00, 35.00);
  humedad_DHT11=random(25.00, 95.00);
  velocidad=random(1.00, 30.00);
  direccion=random(0, 360);
  lluvia=random(0, 10);

  // set the fields with the values
  ThingSpeak.setField(1,temp_DHT11);
  ThingSpeak.setField(2,humedad_DHT11);
  ThingSpeak.setField(3,velocidad);
  ThingSpeak.setField(4,direccion);
  ThingSpeak.setField(5,lluvia);
  */
}

void plotCanalSerie() {  // Visualizar datos por canal serie
  //Serial.begin(9600);
  delay(50);
  Serial.print("Temperature DHT11 = ");
  Serial.print(temp_DHT11);
  Serial.println("ºC");
  Serial.print("Humidity DHT11 = ");
  Serial.print(humedad_DHT11);
  Serial.println(" %");
  Serial.print("Velocidad del viento = ");
  Serial.print(velocidad);
  Serial.println(" m/s");
  Serial.print("Dirección del viento = ");
  Serial.print(direccion);
  Serial.println(" ºN");
  Serial.print("Lluvia = ");
  Serial.print(lluvia);
  Serial.println(" mm3/m");
  Serial.println("--------------------------------");
}

// Wait for a response from the server indicating availability,
// and then collect the response and build it into a string.

String getResponse(){
  String response;
  long startTime = millis();

  delay( 200 );
  while ( client.available() < 1 && (( millis() - startTime ) < TIMEOUT ) ){
        delay( 5 );
  }
  
  if( client.available() > 0 ){ // Get response from server.
     char charIn;
     do {
         charIn = client.read(); // Read a char from the buffer.
         response += charIn;     // Append the char to the string response.
        } while ( client.available() > 0 );
    }
  client.stop();
  client.flush();
        
  return response;
}


void enviar_lecturas() {
  // write to the ThingSpeak channel 
  /*
    
   int x = ThingSpeak.writeFields(myChannelNumber, myWriteAPIKey);
  if(x == 200){
    Serial.println("Channel update successful.");
  }
  else{
    Serial.println("Problem updating channel. HTTP error code " + String(x));
  }
  */
  if (client.connect( THING_SPEAK_ADDRESS , 80 )){
  
    // Build the postData string.  
    // If you have multiple fields, make sure the sting does not exceed 1440 characters.
    String postData= "api_key=" + String(SECRET_WRITE_APIKEY) ;
    postData+= "&field1="+String(temp_DHT11);
    postData+= "&field2="+String(humedad_DHT11);
    postData+= "&field3="+String(velocidad);
    postData+= "&field4="+String(direccion);
    postData+= "&field5="+String(lluvia);       

    // POST data via HTTP.
    Serial.println( "Connecting to ThingSpeak for update..." );
    Serial.println();
        
    client.println( "POST /update HTTP/1.1" );
    client.println( "Host: api.thingspeak.com" );
    client.println( "Connection: close" );
    client.println( "Content-Type: application/x-www-form-urlencoded" );
    client.println( "Content-Length: " + String( postData.length() ) );
    client.println();
    client.println( postData );
        
       
    String answer=getResponse();
    Serial.println( answer );
    


    //==================================
    Serial.println("Conectado");
  } else {
    Serial.println("Fallo en la conexion");
  }
  if (!client.connected()) {
    Serial.println("Disconnected!");
  }

  
  
}

void loop() {
  HacerLecturas();
  enviar_lecturas();
  plotCanalSerie();
  delay(300000); // Wait 5 min to update the channel again
  //delay(1000);
}

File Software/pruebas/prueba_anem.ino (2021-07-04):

#define HALL_OUT A0
#define ANEM_OUT A1

float velocidad, direccion;
int offset=18;
int a=0;

void setup() {
  Serial.begin(115200);  //Initialize serial
  Serial.println("INICIANDO");
  Serial.println("Setup terminado correctamente.");
  delay(100);
}

void HacerLecturas() {
  velocidad = analogRead(ANEM_OUT);
  direccion = map(analogRead(HALL_OUT), 0, 1024, 360-offset, 0-offset);
  if (direccion < 0){direccion+=360;}
}

void plotCanalSerie() {  // Visualizar datos por canal serie
  Serial.print("Voltaje = ");
  Serial.println(velocidad);
  Serial.print("Dirección del viento = ");
  Serial.print(direccion);
  Serial.println(" ºN");
  Serial.print("--------------------------------");
  Serial.println(a);
  a++;
}

void loop() {
  HacerLecturas();
  plotCanalSerie();
  delay(200); // Wait 300 seconds to update the channel again
}

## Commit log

2021-07-03 archivos iniciales, piezas 3D
    [balancin.stl, base_anem_veleta.stl, base_pluviometro.stl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]
2021-07-03 Creado el archivo para las claves
2021-07-04 Completando el repositorio
2021-07-04 Actualizando archivo Funcionamiento/README.md para que se vea el video
2021-07-04 Insertar vídeo
2021-07-04 Completando el repositorio/Funcionamiento
